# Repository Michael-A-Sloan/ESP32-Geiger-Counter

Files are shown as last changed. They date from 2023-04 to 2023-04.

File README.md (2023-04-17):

# ESP32-Geiger-Counter
ESP32 Geiger Counter "Fundamentals of Nuclear Engineering" "Project"

The IDE used was the Arduino IDE

Main File is esp32-geiger-counter.ino

If you switch IDE please update the main file to main.cpp

# IoT Geiger Counter with ESP32, OLED Display, Thingspeak Channel and MQTT

- Measures radioactive gamma and beta radiation with quite good resolution at the typical low levels of the natural radiation (due to the big SBM-20 tube)
- Displays the current counts per minute (CPM), estimated dose equivalent rate in micro-Sievert per hour (µS/h) and 10 minutes history with 5 second resolution as bargraph
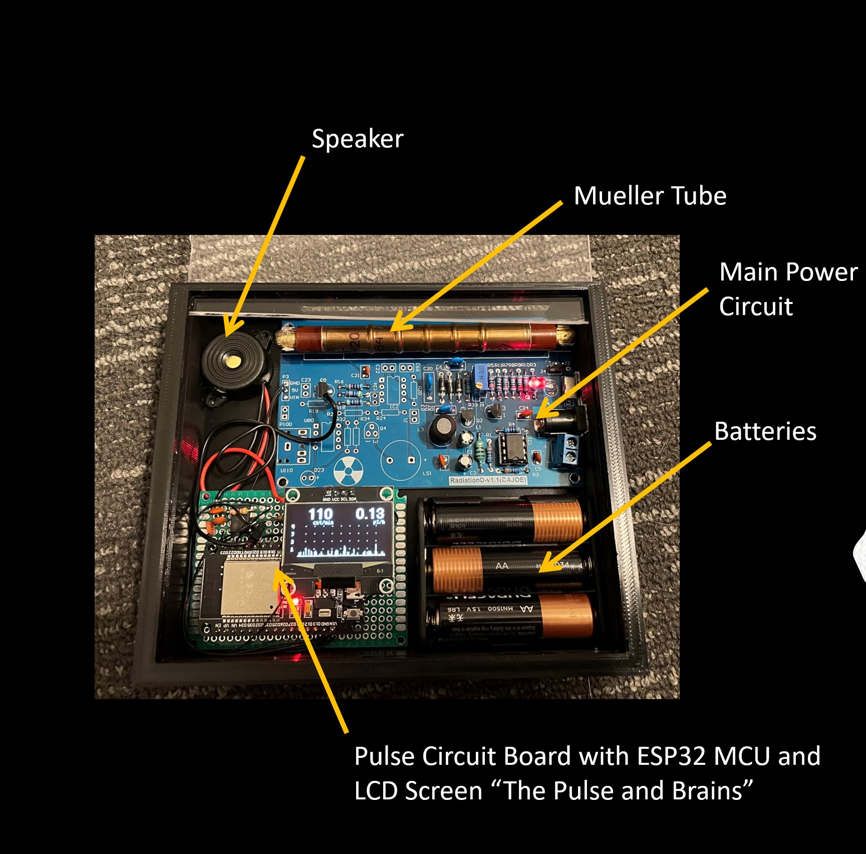
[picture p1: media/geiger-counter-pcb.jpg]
Circuit Board

- Low-power mode for use with batteries, OLED display and click sounds on, WiFi off
- WiFi mode for
  - optional thingspeak data upload every minute, see https://thingspeak.com/channels/......
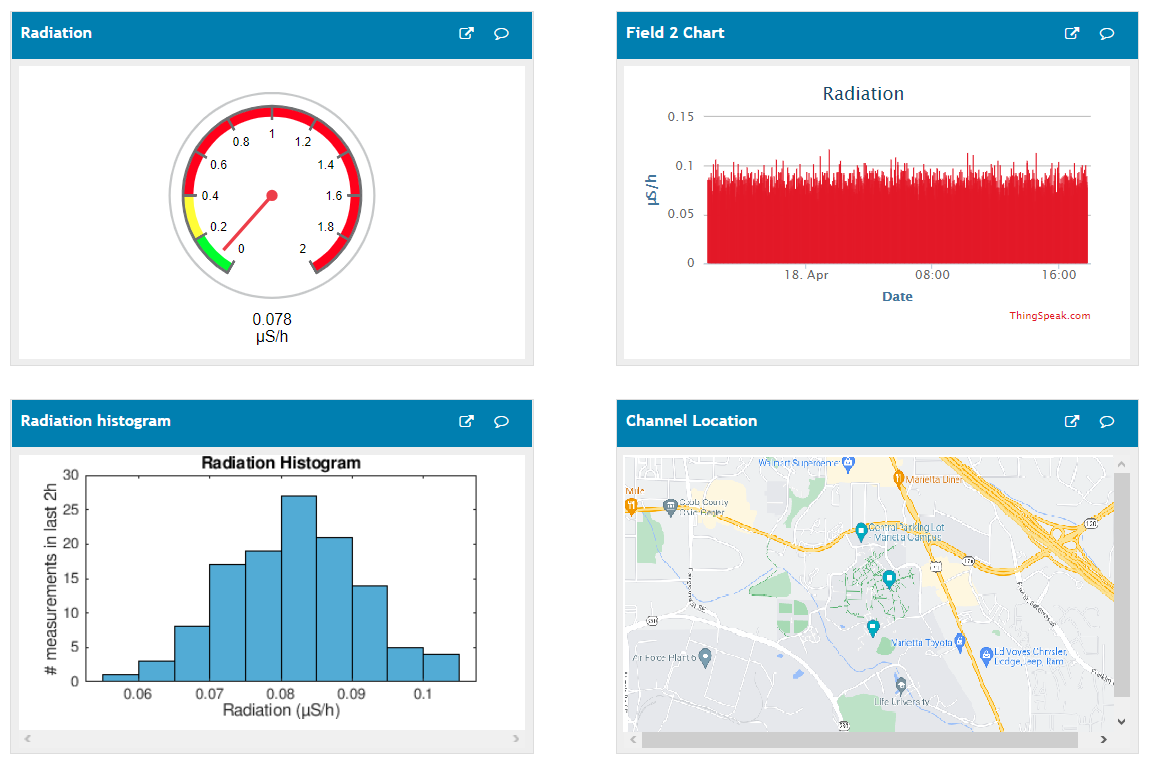
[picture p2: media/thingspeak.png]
https://thingspeak.com/channels/......
[
  - MQTT publishing to a broker every minute with optional SSL/TLS support

Feel free to use this project as a base for your own projects AT YOUR OWN RISK!

# Hardware

- Russian Geiger counter tube SBM-20 at 400 V with ~5 M&#937; series resistor
- High voltage circuit from ArnoR at mikrocontroller.net https://www.mikrocontroller.net/topic/380666, schematic https://www.mikrocontroller.net/attachment/273334/HystereseStepUpTLC555-2.png. *Keep the high-voltage capacitor small to avoid dangerous charges! For safety avoid any contact with the high voltage parts!*
- ~400 µs pulse generation using Geiger tube series resistors as voltage divider, high impedance input to darlington transistor and TLC 555 timer for rectangle pulse generation (schematic and pulses see below)
- ESP32 board EzSBC ESP32-01
- OLED 128x64 with controller SH1106 at I2C
- Voltage supply from either USB or power supply or 3x 1.5V AAA batteries, circuit works stable from 3.0 V up to 5.0 V
- Pulse input is expected at GPIO 15 (high pulses with at least about 250 µs length)
- Switch for WiFi mode is expected at GPIO 4 (low=WiFi mode, high=low-power mode)
- OLED I2C bus is expected at GPIO 22 (SCK) and 21 (SDA)
- Pins may be adjusted in `main.cpp`

# Software

- [Arduino IDE](https://www.arduino.cc/en/software), [Espressif ESP-IDF](https://github.com/espressif/esp-idf) for sleep functions, [U8g2](https://github.com/olikraus/u8g2) for display output and [Arduino-MQTT](https://github.com/256dpi/arduino-mqtt).
- Low-power mode uses light sleep, a wake-up for each signal pulse change and a wake-up every 1000 ms to update pulse statistics and OLED. This results in about 90% sleep. Could be improved using deep sleep and ULP. However, light sleep is already quite good and much easier.
- WiFi mode uses no sleep and simple interrupts for pulse counting. Pulse statistics and OLED are updated every 1000 ms, data is sent to thingspeak every 60 s.
- Credentials, addresses and user for WiFi, thingspeak channel and mqtt broker are declared in `credentials.h` and replaced by dummy values in `credentials.cpp` by default. Define your real secrets in a sibling file named `secret_credentials.h` (do never commit!). It will be automatically included by `credentials.cpp` if it exists. You may copy `TEMPLATE_secret_credentials.h` as a starting point.

# MQTT Message Format

Published messages have the following JSON format:
```json
{
  "pulses": 69,
  "cpm": 69,
  "uSph": 0.08,
  "secs": 60
}
```

# Geiger Tube Pulse Forming

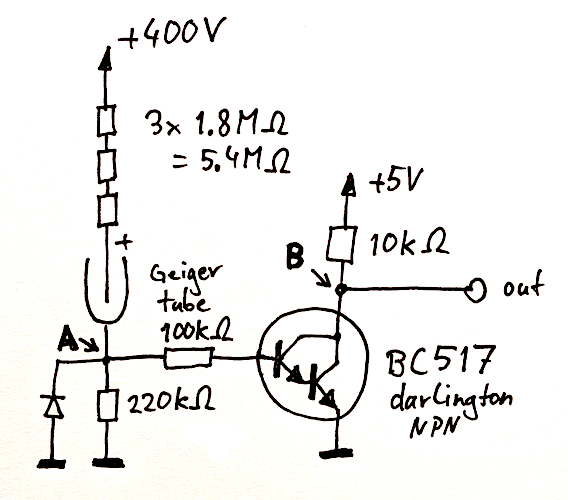
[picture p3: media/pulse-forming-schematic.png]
Pulse forming schematic


The 5.4 M&#937; series resistor is split up to reduce the voltage on each of them. The diode partially removes the noise spikes from the high voltage circuit.

This is the raw pulse at point A, about 2 V for less than 100 µs, then falling back to 0 V in the next several 100 µs. Remainings of the little noise spikes are still visible:

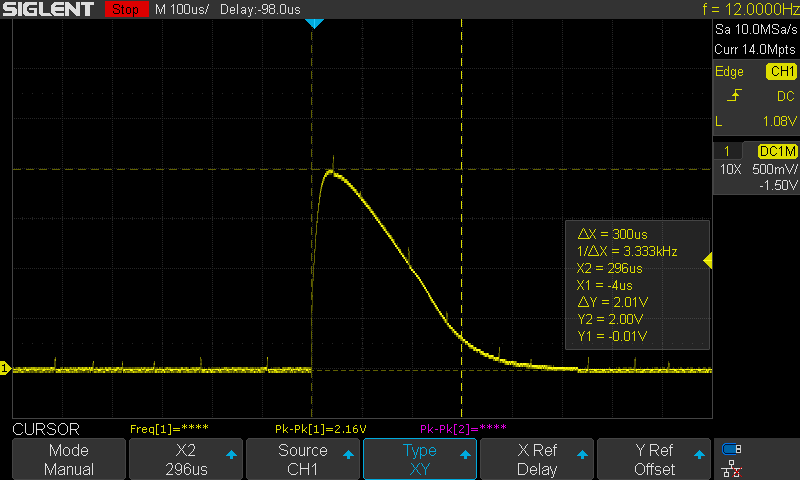
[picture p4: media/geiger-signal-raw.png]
Raw pulse at point A


This is the formed pulse at point B, from 5 V to about 0.5 V for 200 µs:

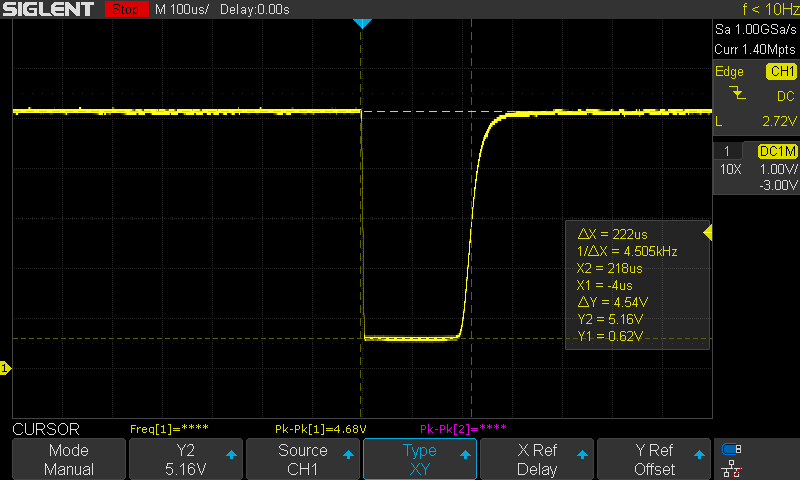
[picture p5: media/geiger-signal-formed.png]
Formed pulse at output point B


It is then fed into a 555 timer to further extend its duration for the ESP32 wake-up from low-power mode.

# Schematic

Hardware / KiCad files are located in folder `hardware`. Currently only schematic, no PCB.

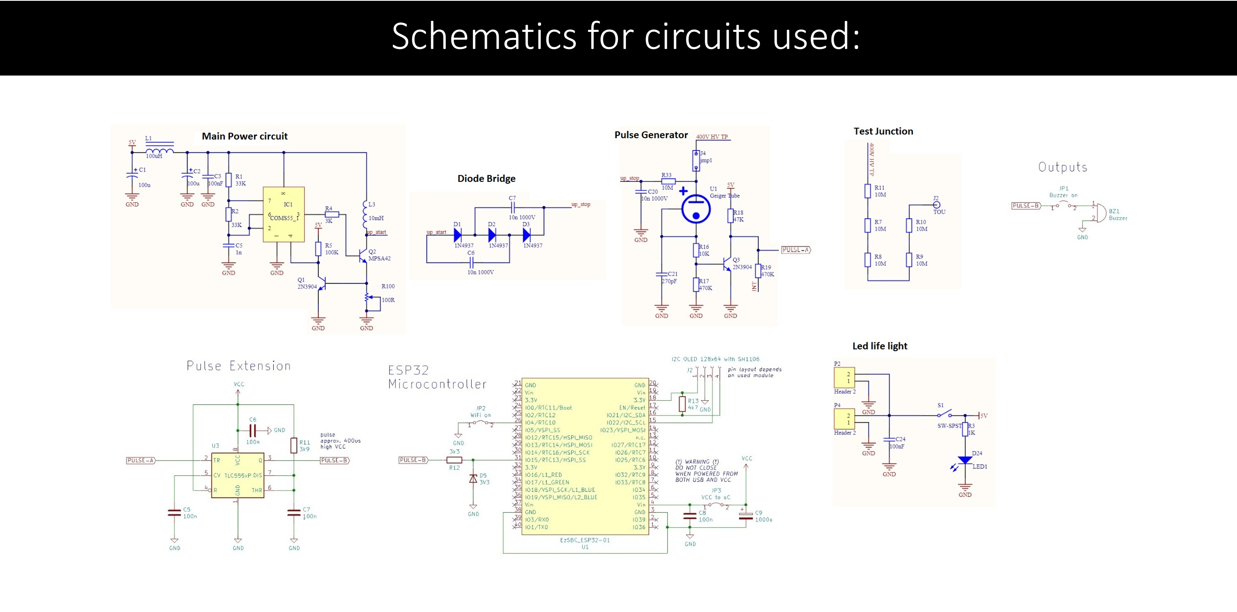
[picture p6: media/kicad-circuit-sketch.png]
Schematics


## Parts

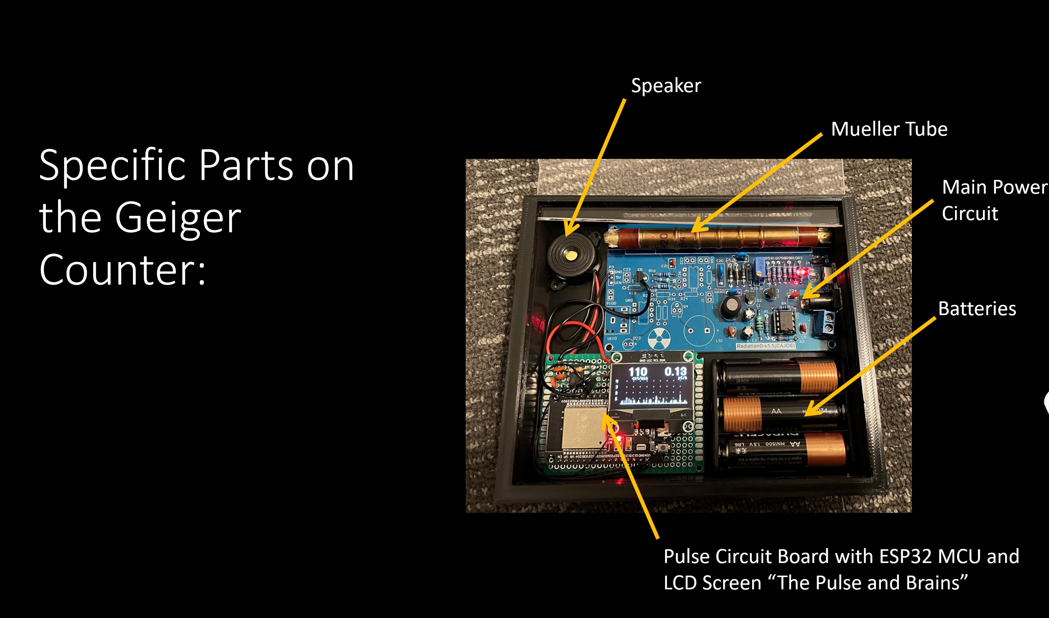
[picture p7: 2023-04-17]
hardware/Geiger_Counter_Parts.jpg

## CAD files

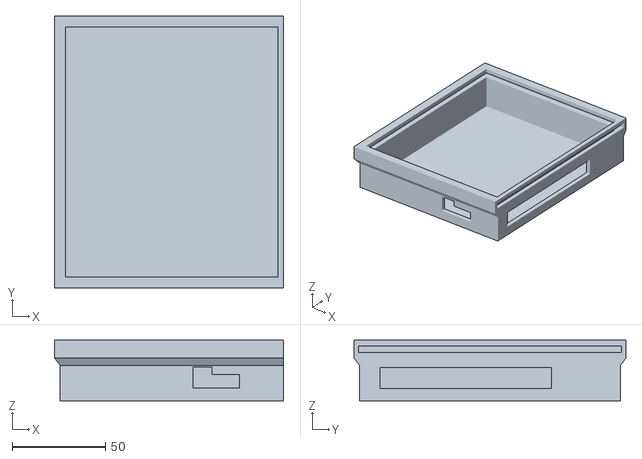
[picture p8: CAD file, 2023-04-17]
hardware/3dPrinter_STL/esp32-geiger-counter v8.stl
123.0 x 146.0 x 32.5

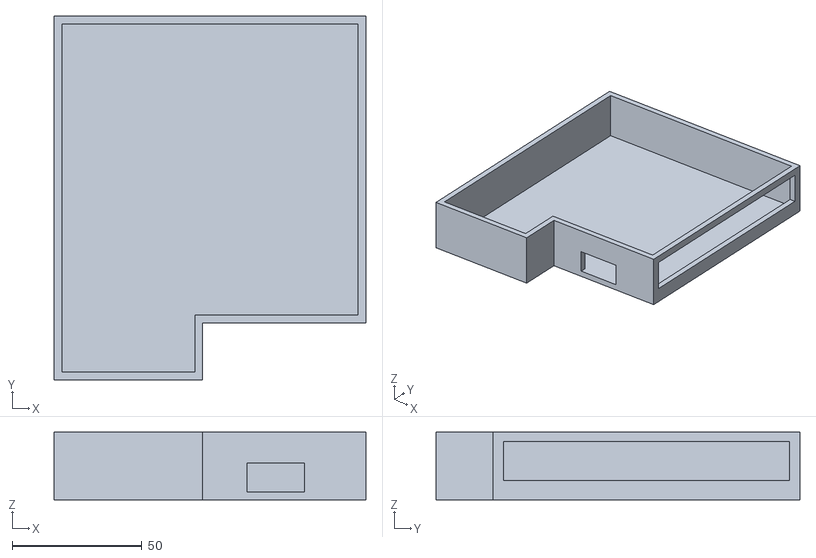
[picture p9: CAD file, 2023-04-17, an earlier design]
hardware/3dPrinter_STL/esp32-geiger-counter v3.stl
120.0 x 140.0 x 26.0

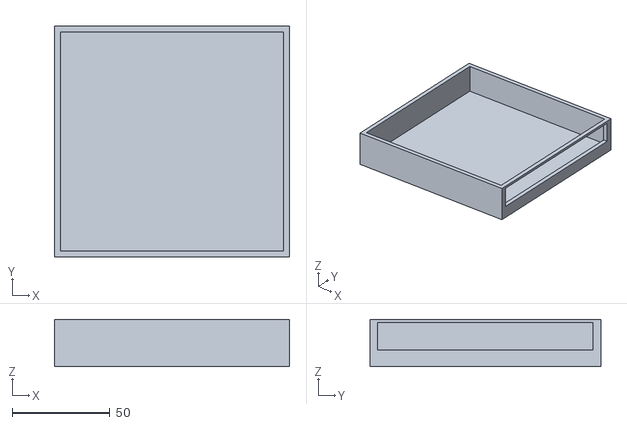
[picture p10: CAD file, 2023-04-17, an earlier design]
hardware/3dPrinter_STL/esp32-geiger-counter v0.stl
120.0 x 118.0 x 24.0

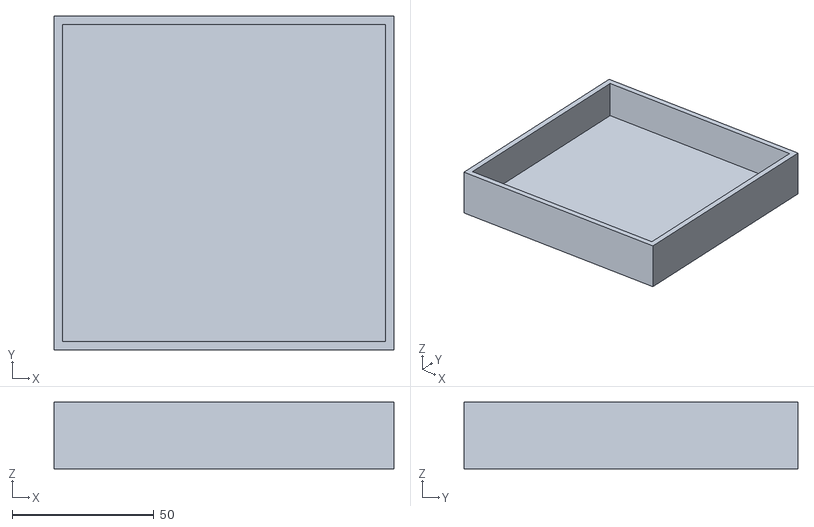
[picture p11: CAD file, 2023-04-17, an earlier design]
hardware/3dPrinter_STL/esp32-geiger-counter v1.stl
120.0 x 118.0 x 23.6

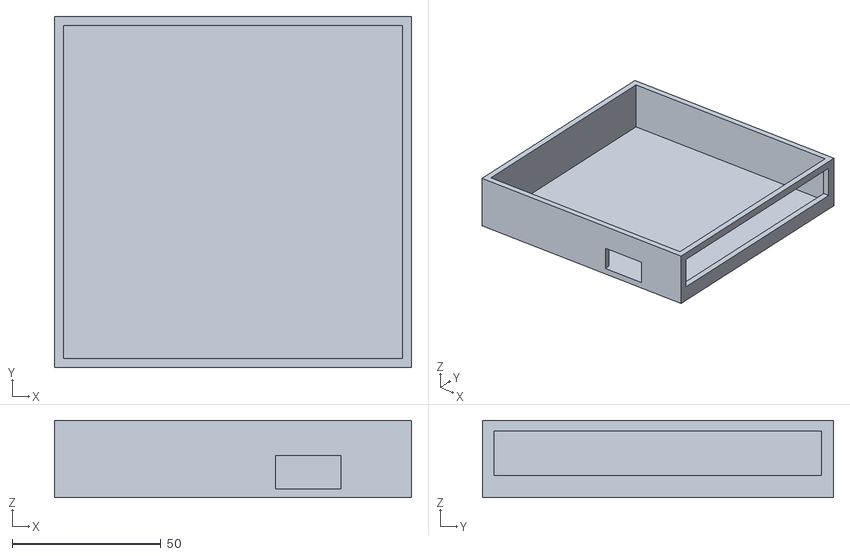
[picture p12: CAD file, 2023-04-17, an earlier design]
hardware/3dPrinter_STL/esp32-geiger-counter v2.stl
120.0 x 118.0 x 26.0

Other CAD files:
hardware/3dPrinter_STL/esp32-geiger-counter v7.stl
hardware/3dPrinter_STL/esp32-geiger-counter v5.stl

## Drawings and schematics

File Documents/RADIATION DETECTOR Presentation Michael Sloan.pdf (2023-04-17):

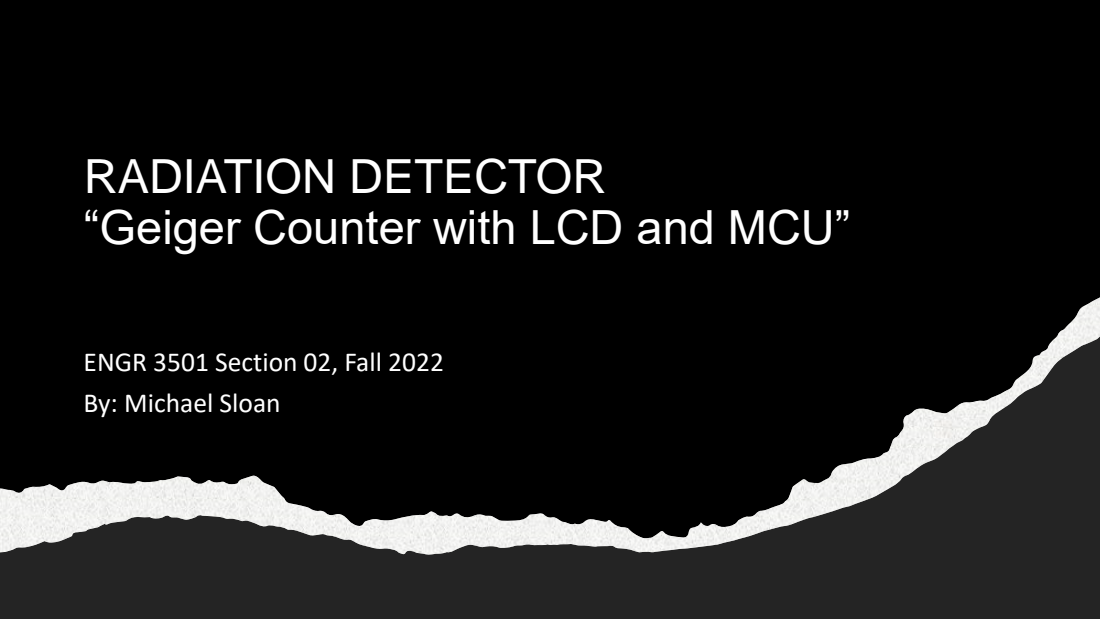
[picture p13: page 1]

RADIATION DETECTOR
“Geiger Counter with LCD and MCU”

ENGR 3501 Section 02, Fall 2022
By: Michael Sloan

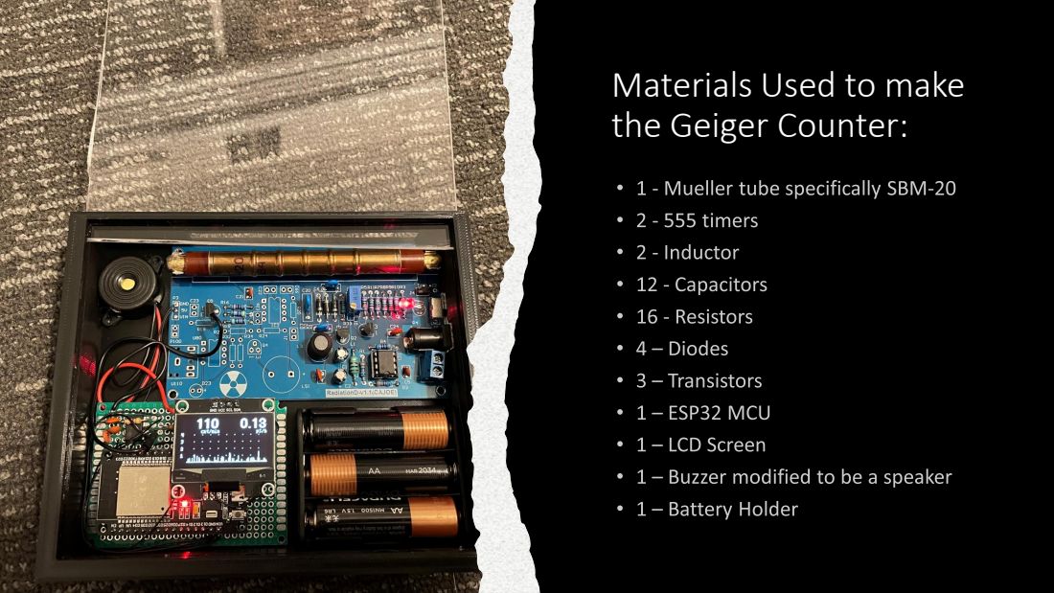
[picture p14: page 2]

Materials Used to make
the Geiger Counter:

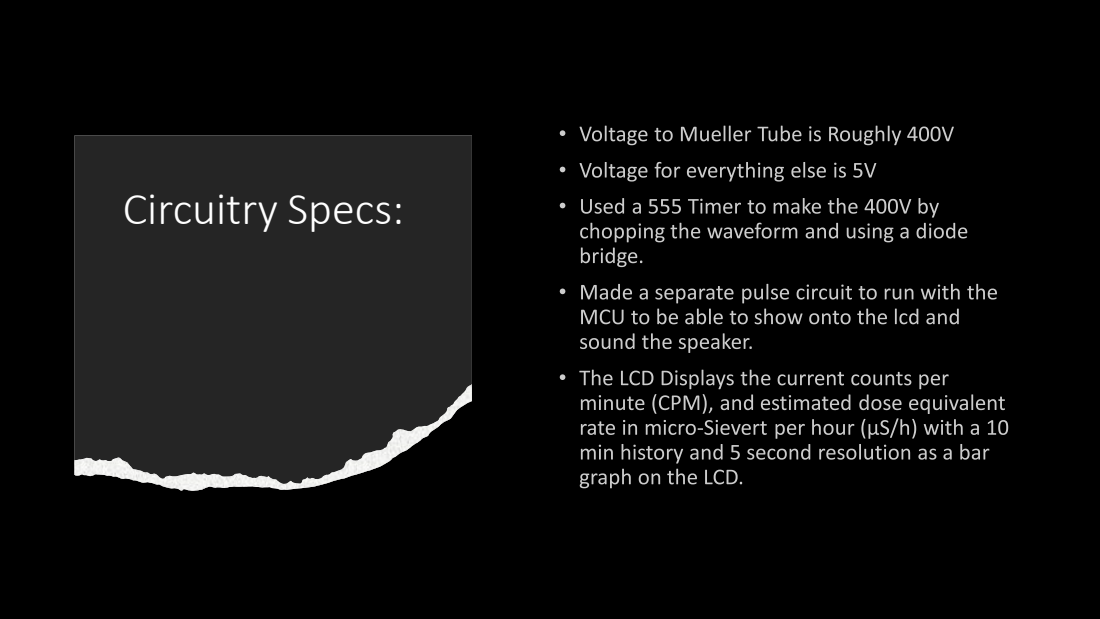
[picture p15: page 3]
Circuitry Specs:

Schematics for circuits used:

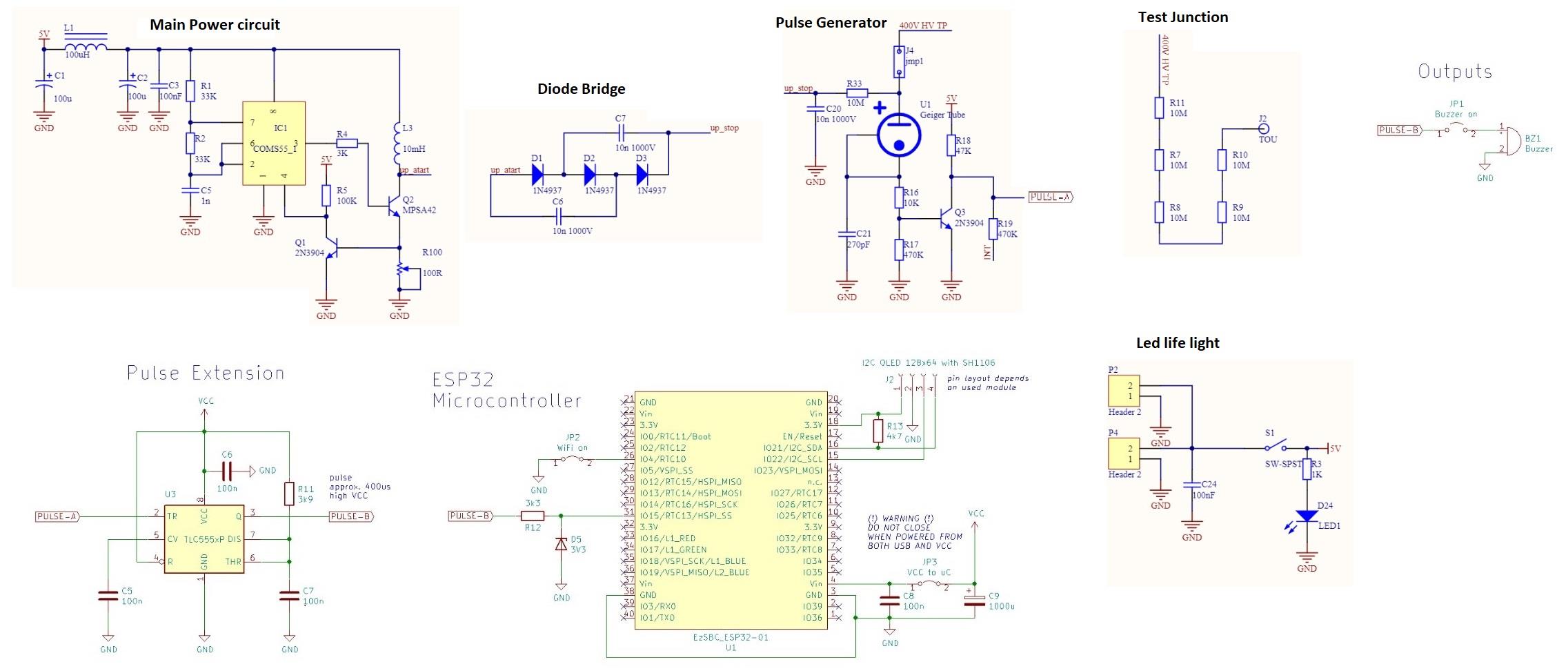
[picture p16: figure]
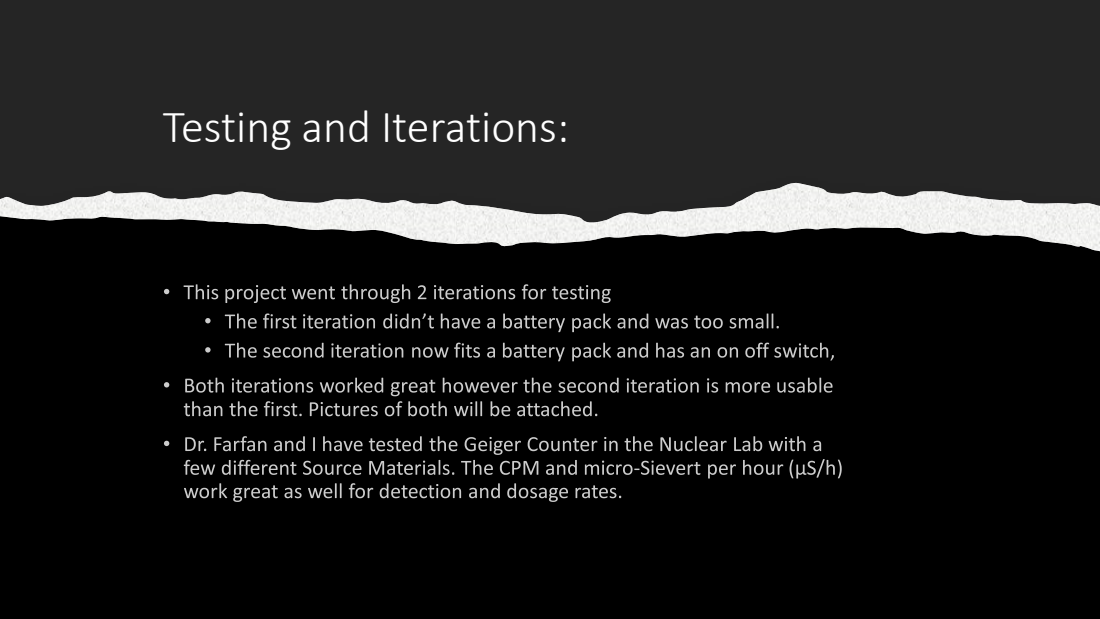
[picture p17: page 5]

Testing and Iterations:

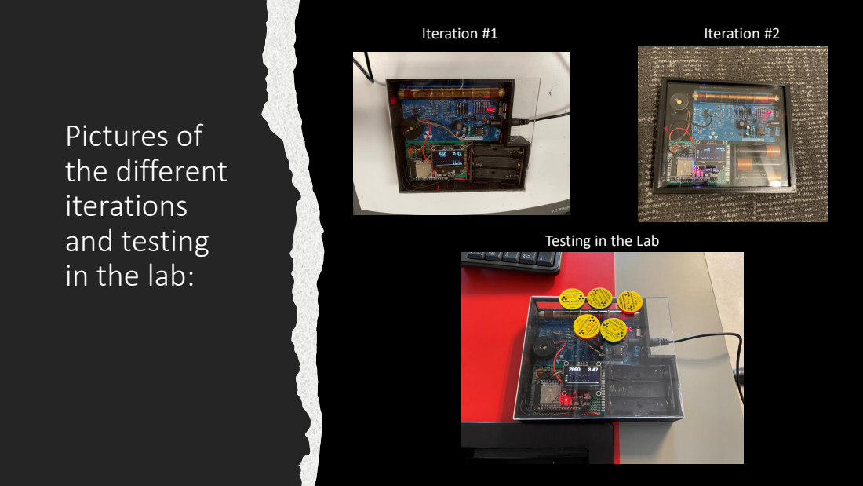
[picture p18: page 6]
Iteration #1; Iteration #2

Pictures of
the different
iterations
and testing
in the lab:

Testing in the Lab

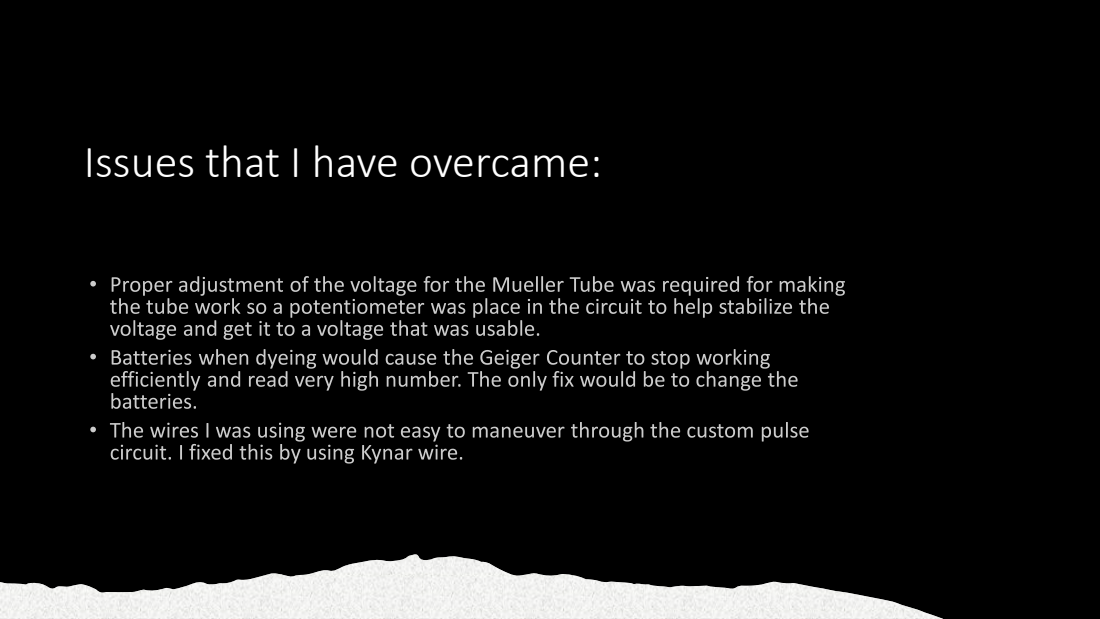
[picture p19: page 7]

Issues that I have overcame:

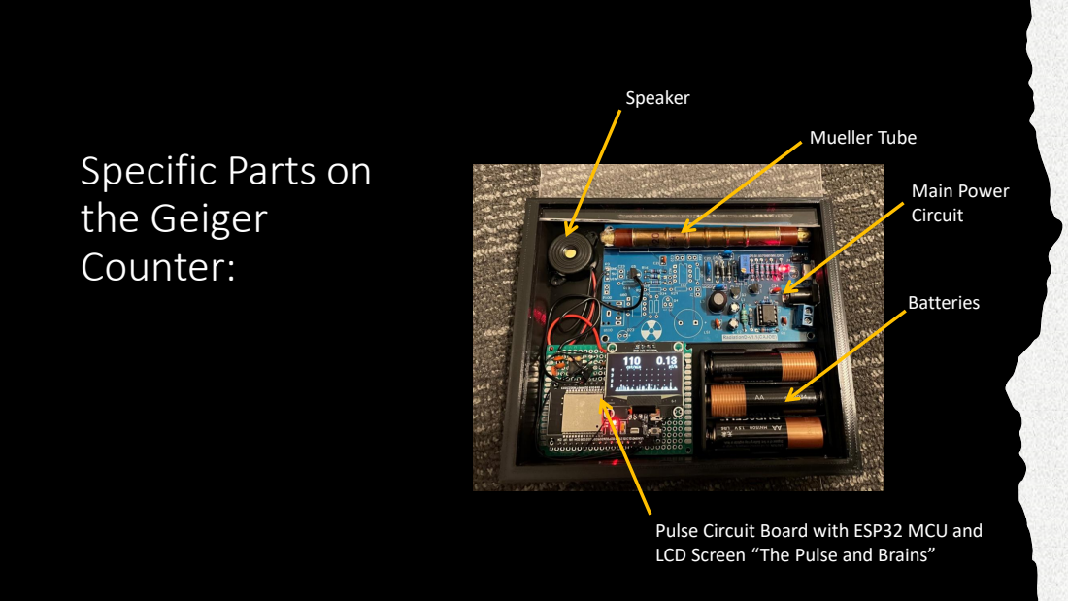
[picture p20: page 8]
Main Power Circuit; Mueller Tube; Speaker; Batteries

Specific Parts on
the Geiger
Counter:

Pulse Circuit Board with ESP32 MCU and
LCD Screen “The Pulse and Brains”

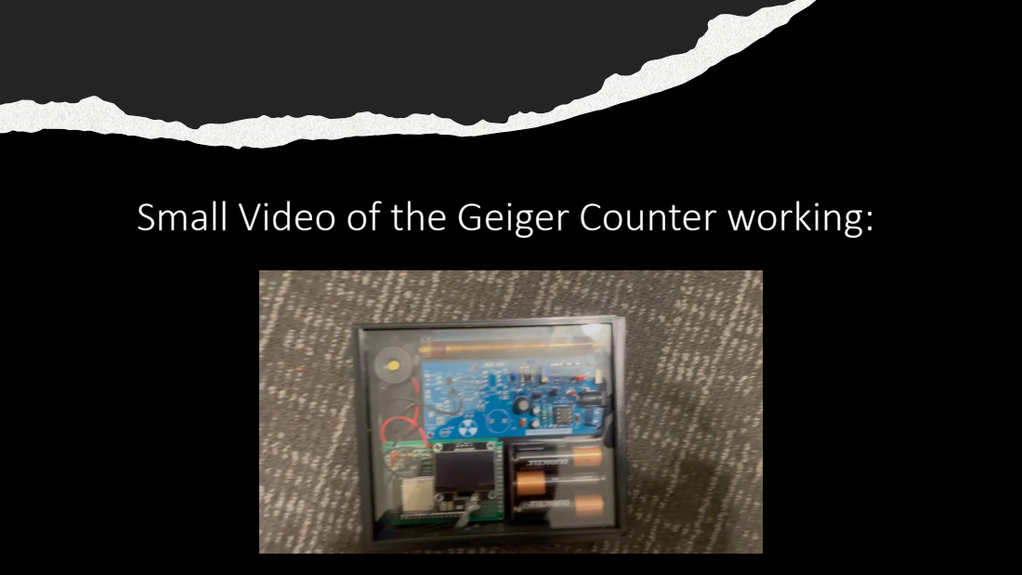
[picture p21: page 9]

Small Video of the Geiger Counter working:

Thank you for your time and watching my presentation of my Geiger Counter

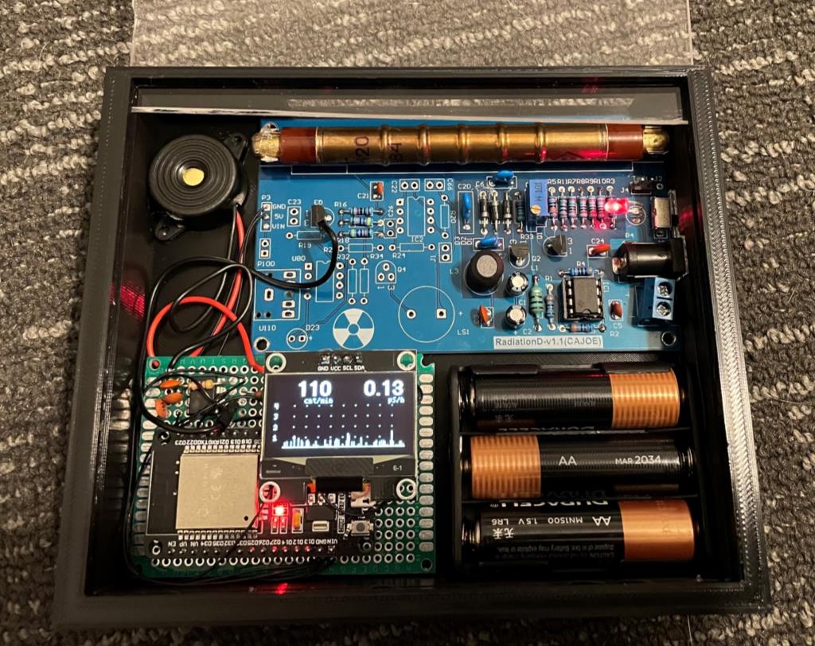
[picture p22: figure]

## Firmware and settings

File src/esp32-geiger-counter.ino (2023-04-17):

#include <Arduino.h>
#include "driver/pcnt.h"
#include "driver/gpio.h"
#include "driver/rtc_io.h"
#include "display.h"
#include "ingest.h"
#include "GeigerData.h"

// ~400µs high pulses from Geiger tube on GPIO 18
#define PULSE_PIN 4
#define PULSE_GPIO GPIO_NUM_4

// switch input for WiFi on (low) and off (high)
#define WIFI_SWITCH_PIN 15

// blinky LED
#define BLINKY_LED_PIN 2

// Keep 600 samples of 1s in history (10 minutes),
// calculate radiation for russian STS-6 ("CTC-6") Geiger tube
GeigerData geigerData(600, 1, STS6_CPM_PER_USPH);

// blinky state
int blinky = 1;

// Pulses counted by interrupt (while CPU is awake)
volatile uint16_t intPulseCount = 0;
// Pulses counted during ESP light sleep
volatile uint16_t pulseCount = 0;

// Sample duration in µs
const uint32_t sampleMicros = geigerData.sampleSeconds * 1000000;
// Absolute sample interval start micros
uint32_t sampleStart = 0;

const int16_t ingestInterval = 60;
int16_t ingestCountdown;

const int watchdogTimeoutMicros = 40000000L;
hw_timer_t *watchdogTimer = NULL;

void pulse();
uint32_t calcRemainingWait();
boolean wifiSwitchOn();
uint16_t takeSampleNoSleep();
uint16_t takeSampleLowPower();
void IRAM_ATTR watchdogExpired();

void setup()
{
  Serial.begin(115200);
  Serial.println("Starting!");


  // initialize watchdog timer
  watchdogTimer = timerBegin(0, 80, true);
  timerAttachInterrupt(watchdogTimer, &watchdogExpired, true);
  timerAlarmWrite(watchdogTimer, watchdogTimeoutMicros, false);
  timerAlarmEnable(watchdogTimer);

  // OLED
  initDisplay();

  // blinky
  pinMode(BLINKY_LED_PIN, OUTPUT);

  // Geiger pulse input
  pinMode(PULSE_PIN, INPUT);

  // WiFi switch input
  pinMode(WIFI_SWITCH_PIN, INPUT_PULLUP);
  if (wifiSwitchOn())
  {
    initIngest();
  }

  // initialize sample start
  sampleStart = micros();
  ingestCountdown = ingestInterval;
}

void loop()
{
  // blinky

  digitalWrite(BLINKY_LED_PIN, blinky);
  blinky = !blinky;

  // reset watchdog
  timerWrite(watchdogTimer, 0);

  const uint16_t pulses =
    wifiSwitchOn() ? takeSampleNoSleep() : takeSampleLowPower();

  geigerData.addPulses(pulses);
  geigerData.nextSample();

  if (wifiSwitchOn())
  {
 //   loopIngest();
    ingestCountdown--;
    if (ingestCountdown <= 0)
    {
      ingestCountdown = ingestInterval;
      ingestToThingspeak(geigerData, ingestInterval);
//      ingestToMqtt(geigerData, ingestInterval);
    }
  }
  else
  {
    deinitIngest();
  }

  // determine current value, average 6 seconds
  // because this is very near to the 5 seconds history
  // bar width and gives nicely rounded count values

  const uint16_t samples = 6;
  const uint32_t prevPulses = geigerData.getPreviousPulses(1, samples);
  const uint32_t cpm = prevPulses * (60 / samples);
  const float uSph = geigerData.toMicroSievertPerHour(prevPulses, samples);

  // test for display layout:
  // const uint32_t cpm = 1000*60;
  // const float uSph = geigerData.toMicroSievertPerHour(cpm, 60);

  char cpmStr[16];
  ltoa(cpm, cpmStr, 10);
  char uSphStr[16];
  sprintf(uSphStr, "%.2f", uSph);

  // serial output cpm and µS/h

  Serial.print(pulses);
  Serial.print(" ");
  Serial.print(cpmStr);
  Serial.print(" ");
  Serial.println(uSphStr);

  updateDisplay(geigerData, uSphStr, cpmStr);
}

// interrupt handler
void pulse()
{
  ++intPulseCount;
}

uint32_t calcRemainingWait()
{
  const uint32_t remaining = sampleMicros - (micros() - sampleStart);
  return remaining > sampleMicros ? 0 : remaining;
}

boolean wifiSwitchOn()
{
  return digitalRead(WIFI_SWITCH_PIN) == 0;
}

uint16_t takeSampleNoSleep()
{
  attachInterrupt(PULSE_PIN, pulse, RISING);

  int32_t remainingWait = calcRemainingWait();
  delayMicroseconds(remainingWait);
  sampleStart = micros();
  noInterrupts();
  const int16_t pulses = intPulseCount;
  intPulseCount = 0;
  interrupts();

  return pulses;
}

uint16_t takeSampleLowPower()
{
  // To save battery power, use light sleep as much as possible.
  // During light sleep, no counters or interrupts are working.
  // Therefore simply wake up on each pulse signal change. This
  // is fast enough for the low frequencies from a Geiger tube
  // (below 2kHz):
  // Wake up at end of sample period. Also
  // wake up on pulse getting high and getting low.
  // Waking up directly on rising/falling edges is not possible,
  // so wait until level change.
  // Switch to interrupt counting while awake for calculations
  // and display update.

  // stop interrupt (switch to active wakeup counting loop):
  detachInterrupt(PULSE_PIN);

  int32_t remainingWait = calcRemainingWait();
  esp_sleep_wakeup_cause_t cause = ESP_SLEEP_WAKEUP_UNDEFINED;
  while (cause != ESP_SLEEP_WAKEUP_TIMER && remainingWait > 0)
  {

    if (digitalRead(PULSE_PIN))
    {
      // wait for low pulse start or sample time end
      esp_sleep_enable_timer_wakeup(remainingWait);
      gpio_wakeup_enable(PULSE_GPIO, GPIO_INTR_LOW_LEVEL);
      esp_sleep_enable_gpio_wakeup();
      esp_light_sleep_start();
      cause = esp_sleep_get_wakeup_cause();
    }

    remainingWait = calcRemainingWait();
    if (cause != ESP_SLEEP_WAKEUP_TIMER && remainingWait > 0)
    {
      // wait for high pulse start or sample time end
      esp_sleep_enable_timer_wakeup(remainingWait);
      gpio_wakeup_enable(PULSE_GPIO, GPIO_INTR_HIGH_LEVEL);
      esp_sleep_enable_gpio_wakeup();
      esp_light_sleep_start();
      cause = esp_sleep_get_wakeup_cause();
      if (cause == ESP_SLEEP_WAKEUP_GPIO)
      {
        ++pulseCount;
      }
    }

    remainingWait = calcRemainingWait();
  }

  // take sample and add to statistics

  sampleStart = micros();
  const int16_t pulses = pulseCount + intPulseCount;
  //  Serial.print("pc=");
  //  Serial.print(pulseCount);
  //  Serial.print(" ipc=");
  //  Serial.println(intPulseCount);
  attachInterrupt(PULSE_PIN, pulse, RISING);
  interrupts();
  // reset counters AFTER enabling interrupt to avoid double-counting on high signal
  pulseCount = 0;
  intPulseCount = 0;

  return pulses;
}

void IRAM_ATTR watchdogExpired()
{
  esp_restart();
}

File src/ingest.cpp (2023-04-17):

#include <WiFi.h>
#include <WiFiClientSecure.h>
//#include "MQTT.h"

#include "GeigerData.h"

#include "credentials.h"

const char *thingsPeakUrl = "api.thingspeak.com";

WiFiClient mqttWifiClient;
WiFiClientSecure mqttWifiClientSecure;
//MQTTClient mqttClient;

bool connectWiFi()
{
	WiFi.persistent(false);

	uint16_t retries = 10;
	while (WiFi.status() != WL_CONNECTED && (retries--) > 0)
	{
		Serial.print("Trying to connect to ");
		Serial.print(wifiSsid);
		Serial.print(" ... ");
		WiFi.begin(wifiSsid, wifiPassword);
		uint16_t waitRemaining = 8;
		while (WiFi.status() != WL_CONNECTED && (--waitRemaining) > 0)
		{
			delay(500);
		}
		if (WiFi.status() == WL_CONNECTED)
		{
			Serial.println("successful");
			return true;
		}
		else
		{
			Serial.print("failed status=");
			Serial.println(WiFi.status());
		}
	}

	return WiFi.status() == WL_CONNECTED;
}

void disconnectWiFi()
{
	Serial.println("Disconnecting WiFi");
	WiFi.disconnect(true, true);
}

void initIngest()
{
	connectWiFi();
}

/*void loopIngest()
{
	if (mqttClient.connected())
	{
		mqttClient.loop();
	}
}*/

void deinitIngest()
{
	if (WiFi.status() == WL_CONNECTED)
	{
		disconnectWiFi();
	}
}

void ingestToThingspeak(GeigerData &geigerData, uint16_t intervalSamples)
{
	if (!connectWiFi())
		return;

	if (thingsPeakUrl == NULL || thingsPeakUrl[0] == 0)
		return;

	WiFiClient client;
	if (!client.connect(thingsPeakUrl, 80))
	{
		Serial.print("Connecting to ");
		Serial.print(thingsPeakUrl);
		Serial.println(" failed");
		// disconnect from WiFi to trigger fresh connect on next ingest
		disconnectWiFi();
	}
	else
	{
		client.setTimeout(30);

		const uint32_t pulses = geigerData.getPreviousPulses(1,
															 intervalSamples);
		const uint32_t cpm = uint32_t(
			pulses / ((float)intervalSamples * geigerData.sampleSeconds / 60.) + 0.5);
		const float uSph = geigerData.toMicroSievertPerHour(pulses,
															intervalSamples);

		const String content = "api_key=" + String(thingspeakApiKey) + "&field1=" + String(cpm) + "&field2=" + String(uSph, 3);

		Serial.print("Ingesting cpm=");
		Serial.print(cpm);
		Serial.print(" uSph=");
		Serial.print(uSph, 3);
		Serial.print(" ... ");

		client.print("POST /update HTTP/1.1\n");

		client.print("Host: ");
		client.print(thingsPeakUrl);
		client.print("\n");

		client.print("Connection: close\n");

		client.print("Content-Type: application/x-www-form-urlencoded\n");
		client.print("Content-Length: ");
		client.print(content.length());
		client.print("\n\n");

		client.print(content);

		uint16_t timeout = 40;
		while (client.available() == 0 && (--timeout) > 0)
		{
			delay(50);
		}
		if (client.available() == 0)
		{
			Serial.println("failed (no response)");
		}

		Serial.println("response:");
		while (client.available())
		{
			char c = client.read();
			Serial.write(c);
		}
		Serial.println();

		client.stop();
	}
}

/*bool connectMqtt()
{
	if (!connectWiFi())
		return false;

	if (mqttHost == NULL || mqttHost[0] == 0)
		return false;

	if (!mqttClient.connected())
	{
		const bool tls = mqttTlsServerRootCert != NULL && mqttTlsServerRootCert[0] != 0;
		Serial.print("Connecting to MQTT host ");
		Serial.print(mqttHost);
		Serial.print(":");
		Serial.print(mqttPort);
		Serial.print(" user ");
		Serial.print(mqttUser);
		if (tls) {
			Serial.print(" with TLS ");
			mqttWifiClientSecure.setCACert(mqttTlsServerRootCert);
			mqttClient.begin(mqttHost, mqttPort, mqttWifiClientSecure);
		} else {
			Serial.print(" without TLS ");
			mqttClient.begin(mqttHost, mqttPort, mqttWifiClient);
		}

		if (mqttClient.connect("esp32-geiger-counter", mqttUser, mqttPassword))
		{
			Serial.println(" successful");
		}
		else
		{
			Serial.println(" failed");
			// disconnect from WiFi to trigger fresh connect on next ingest
			disconnectWiFi();
			return false;
		}
	}

	return true;
}*/

/*void disconnectMqtt()
{
	mqttClient.disconnect();
}

void ingestToMqtt(GeigerData &geigerData, uint16_t intervalSamples)
{
	if (connectMqtt())
	{
		const unsigned long pulses = geigerData.getPreviousPulses(1,
																  intervalSamples);
		const unsigned long cpm = (unsigned long)(pulses / ((float)intervalSamples * geigerData.sampleSeconds / 60.) + 0.5);
		const float uSph = geigerData.toMicroSievertPerHour(pulses,
															intervalSamples);
		char payload[129];
		sprintf(payload, "{\"pulses\":%lu, \"cpm\":%lu,\"uSph\":%.3f,\"secs\":%d}",
				pulses, cpm, uSph, (int)intervalSamples);

		if (!mqttClient.publish(mqttTopic, payload))
		{
			mqttClient.disconnect();
		}
	}
}*/
